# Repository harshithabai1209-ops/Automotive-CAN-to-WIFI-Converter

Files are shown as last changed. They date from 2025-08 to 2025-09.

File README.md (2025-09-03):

🚗 Automotive CAN-to-WiFi Converter(PCB DESIGN)
📌 Overview

This project implements an Automotive CAN (Controller Area Network) to Wi-Fi converter using a microcontroller with integrated Wi-Fi and a custom PCB designed in KiCad.
It allows vehicles’ CAN bus data (speed, RPM, fuel level, sensor data, etc.) to be captured, processed, and transmitted over Wi-Fi to mobile apps.

🚀 Features

Interfaces with standard Automotive CAN bus (OBD-II, ISO 11898)

Converts CAN frames into Wi-Fi packets

Supports protocols: MQTT, HTTP, WebSocket

Designed for low-latency data streaming

Custom KiCad PCB with CAN transceiver + Wi-Fi MCU

Optional SD card logging for offline analysis

Can be used for telematics, diagnostics, and fleet monitoring

🛠️ Hardware Components

Microcontroller (ESP32 / STM32 + ESP8266) → Wi-Fi + processing

CAN Transceiver (MCP2551 / SN65HVD230) → Interface between CAN bus & MCU

OBD-II Connector → Connection to vehicle CAN lines (CAN_H, CAN_L)

Power Supply

12V from car → Buck converter → 5V/3.3V regulated

Automotive-grade regulator (LM2596 / MP1584)

Protection Circuits

TVS Diodes for CAN line protection

Fuse & reverse polarity protection

Optional Modules

SD card (logging)

OLED/LCD (local display)

📐 PCB Design (KiCad)

Designed using KiCad EDA

2-layer PCB optimized for automotive use

Includes CAN transceiver + ESP32 footprint

Proper decoupling capacitors and EMI filters

Ground plane isolation between noisy CAN and Wi-Fi section

Connector footprint for OBD-II interface

Gerber files ready for fabrication

⚙️ Firmware / Software

Developed using Arduino IDE / ESP-IDF / STM32Cube

Features:

Reads CAN frames via CAN transceiver

Publishes data over Wi-Fi (MQTT/HTTP/WebSocket)

Supports real-time monitoring dashboard

Configurable baud rates (125 kbps, 250 kbps, 500 kbps)

🧩 Applications

Vehicle diagnostics (OBD-II data monitoring)

Fleet management & telematics

Real-time performance tracking (RPM, speed, fuel, etc.)

Research & development for automotive IoT

Data logging for predictive maintenance

⚠️ Safety Note

⚡ Caution: This project connects directly to the vehicle’s CAN bus. Incorrect wiring may damage ECU or other vehicle electronics. Ensure proper isolation and automotive-grade components are used.

📖 Future Enhancements

Support for Bluetooth + Wi-Fi dual mode

Cloud analytics with AI for predictive maintenance

Encryption for secure vehicle data transfer

Integration with mobile OBD-II diagnostic apps

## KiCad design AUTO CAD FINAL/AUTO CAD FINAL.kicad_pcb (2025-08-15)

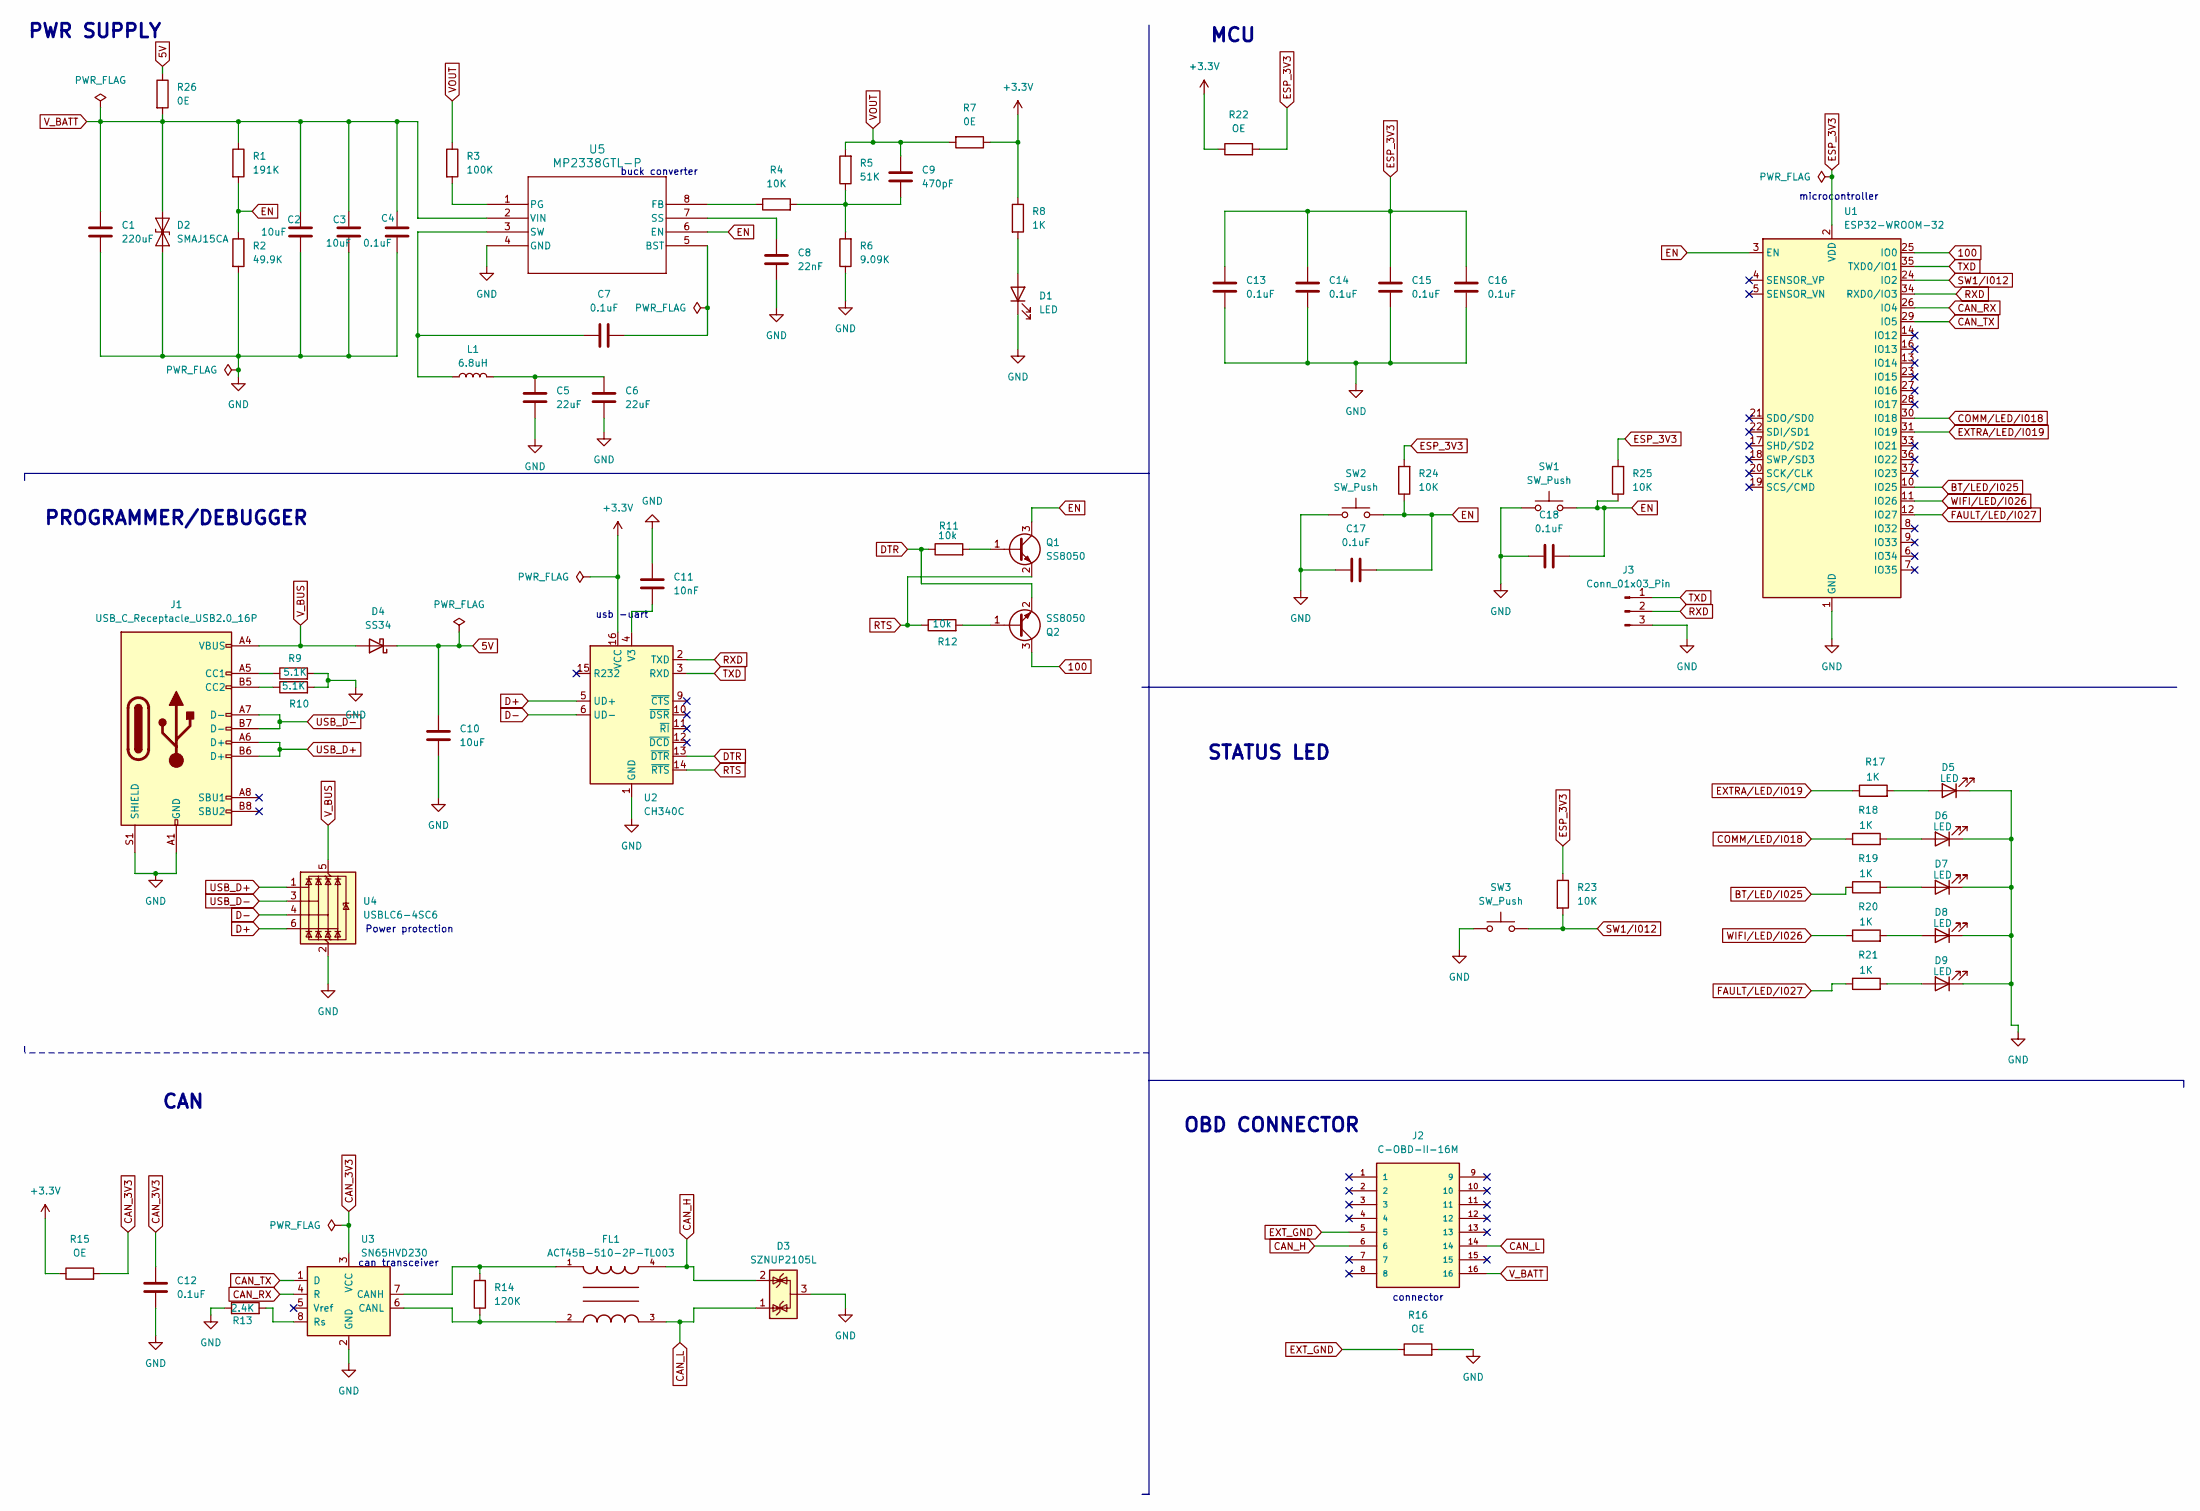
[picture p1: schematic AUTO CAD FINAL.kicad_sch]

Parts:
C1: 220uF; C_Elec_8x10.2
C2, C3, C10: 10uF; C_0603_1608Metric
C4, C7, C12, C13, C14, C15, C16, C17, C18: 0.1uF; C_0603_1608Metric
C5, C6: 22uF; C_1206_3216Metric
C8: 22nF; C_0603_1608Metric
C9: 470pF; C_0603_1608Metric
C11: 10nF; C_0603_1608Metric
D1, D5, D6, D7, D8, D9: LED; LED_0603_1608Metric
D2: SMAJ15CA; D_SMA
D3: SZNUP2105L; SOT-23
D4: SS34; D_SMA
FL1: ACT45B-510-2P-TL003; FIL_ACT45B-510-2P-TL003; PARTREV 20200405
J1: USB_C_Receptacle_USB2.0_16P; USB_C_Receptacle_HRO_TYPE-C-31-M-12
J2: C-OBD-II-16M; COMTECH_C-OBD-II-16M; PARTREV A
J3: Conn_01x03_Pin; PinHeader_1x03_P2.54mm_Vertical
L1: 6.8uH; L_6.3x6.3_H3
Q1, Q2: SS8050; SOT-23
R1: 191K; R_0603_1608Metric
R2: 49.9K; R_0603_1608Metric
R3: 100K; R_0603_1608Metric
R4, R23, R24, R25: 10K; R_0603_1608Metric
R5: 51K; R_0603_1608Metric
R6: 9.09K; R_0603_1608Metric
R7, R26: 0E; R_0603_1608Metric
R8, R17, R18, R19, R20, R21: 1K; R_0603_1608Metric
R9, R10: 5.1K; R_0603_1608Metric
R11, R12: 10k; R_0603_1608Metric
R13: 2.4K; R_0603_1608Metric
R14: 120K; R_0603_1608Metric
R15, R16, R22: OE; R_0603_1608Metric
SW1, SW2, SW3: SW_Push; SW_Push_SPST_NO_Alps_SKRK
U1: ESP32-WROOM-32
U2: CH340C; SOIC-16_3.9x9.9mm_P1.27mm
U3: SN65HVD230; SOIC-8_3.9x4.9mm_P1.27mm
U4: USBLC6-4SC6; SOT-23-6
U5: MP2338GTL-P; SOT-583-8

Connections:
5V: C10.2, D4.1 (K), R26.1
100: Q2.3 (C), U1.25 (IO0)
+3.3V: R7.1, R8.1, R15.1, R22.1, U2.16 (VCC)
BT/LED/I025: R19.1, U1.10 (IO25)
CAN_3V3: C12.2, R15.2, U3.3 (VCC)
CAN_H: D3.2 (K), FL1.4, J2.6
CAN_L: D3.1 (K), FL1.3, J2.14
CAN_RX: U1.26 (IO4), U3.4 (R)
CAN_TX: U1.29 (IO5), U3.1 (D)
COMM/LED/I018: R18.1, U1.30 (IO18)
D+: U2.5 (UD+), U4.6 (I/O4)
D-: U2.6 (UD-), U4.4 (I/O3)
DTR: Q2.2 (E), R11.1, U2.13 (~DTR)
EN: C17.1, C18.1, Q1.3 (C), R1.2, R2.1, R24.1, R25.1, SW1.2, SW2.2, U1.3 (EN), U5.6 (EN)
ESP_3V3: C13.2, C14.2, C15.2, C16.2, R22.2, R23.1, R24.2, R25.2, U1.2 (VDD)
EXTRA/LED/I019: R17.1, U1.31 (IO19)
EXT_GND: J2.5, R16.1
FAULT/LED/I027: R21.1, U1.12 (IO27)
GND: C1.2, C2.2, C3.2, C4.2, C5.2, C6.2, C8.1, C10.1, C11.2, C12.1, C13.1, C14.1, C15.1, C16.1, C17.2, C18.2, D1.1 (K), D2.1 (A1), D3.3 (A), D5.1 (K), D6.1 (K), D7.1 (K), D8.1 (K), D9.1 (K), J1.A1 (GND), J1.A12 (GND), J1.B1 (GND), J1.B12 (GND), J1.S1 (SHIELD), J3.3, R2.2, R6.1, R9.2, R10.2, R13.1, R16.2, SW1.1, SW2.1, SW3.1, U1.1 (GND), U1.15 (GND), U1.38 (GND), U1.39 (GND), U2.1 (GND), U3.2 (GND), U4.2 (GND), U5.4 (GND)
unnamed: C5.1, C6.1, L1.2
unnamed: C9.1, R4.2, R5.1, R6.2
unnamed: D1.2 (A), R8.2
unnamed: D5.2 (A), R17.2
unnamed: D6.2 (A), R18.2
unnamed: D7.2 (A), R19.2
unnamed: D8.2 (A), R20.2
unnamed: D9.2 (A), R21.2
unnamed: J1.A5 (CC1), R9.1
unnamed: J1.B5 (CC2), R10.1
unnamed: Q1.1 (B), R11.2
unnamed: Q2.1 (B), R12.2
unnamed: C11.1, U2.4 (V3)
unnamed: FL1.1, R14.2, U3.7 (CANH)
unnamed: FL1.2, R14.1, U3.6 (CANL)
unnamed: R13.2, U3.8 (Rs)
unnamed: C7.2, U5.5 (BST)
unnamed: R4.1, U5.8 (FB)
unnamed: R3.2, U5.1 (PG)
unnamed: C8.2, U5.7 (SS)
unnamed: C7.1, L1.1, U5.3 (SW)
RTS: Q1.2 (E), R12.1, U2.14 (~RTS)
RXD: J3.2, U1.34 (RXD0/IO3), U2.2 (TXD)
SW1/I012: R23.2, SW3.2, U1.24 (IO2)
TXD: J3.1, U1.35 (TXD0/IO1), U2.3 (RXD)
USB_D+: J1.A6 (D+), J1.B6 (D+), U4.1 (I/O1)
USB_D-: J1.A7 (D-), J1.B7 (D-), U4.3 (I/O2)
VOUT: C9.2, R3.1, R5.2, R7.2
V_BATT: C1.1, C2.1, C3.1, C4.1, D2.2 (A2), J2.16, R1.1, R26.2, U5.2 (VIN)
V_BUS: D4.2 (A), J1.A4 (VBUS), J1.A9 (VBUS), J1.B4 (VBUS), J1.B9 (VBUS), U4.5 (VBUS)
WIFI/LED/I026: R20.1, U1.11 (IO26)

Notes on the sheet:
MCU
usb -uart
connector
can transceiver
microcontroller
OBD CONNECTOR
CAN
PWR SUPPLY
buck converter
Power protection
PROGRAMMER/DEBUGGER
STATUS LED

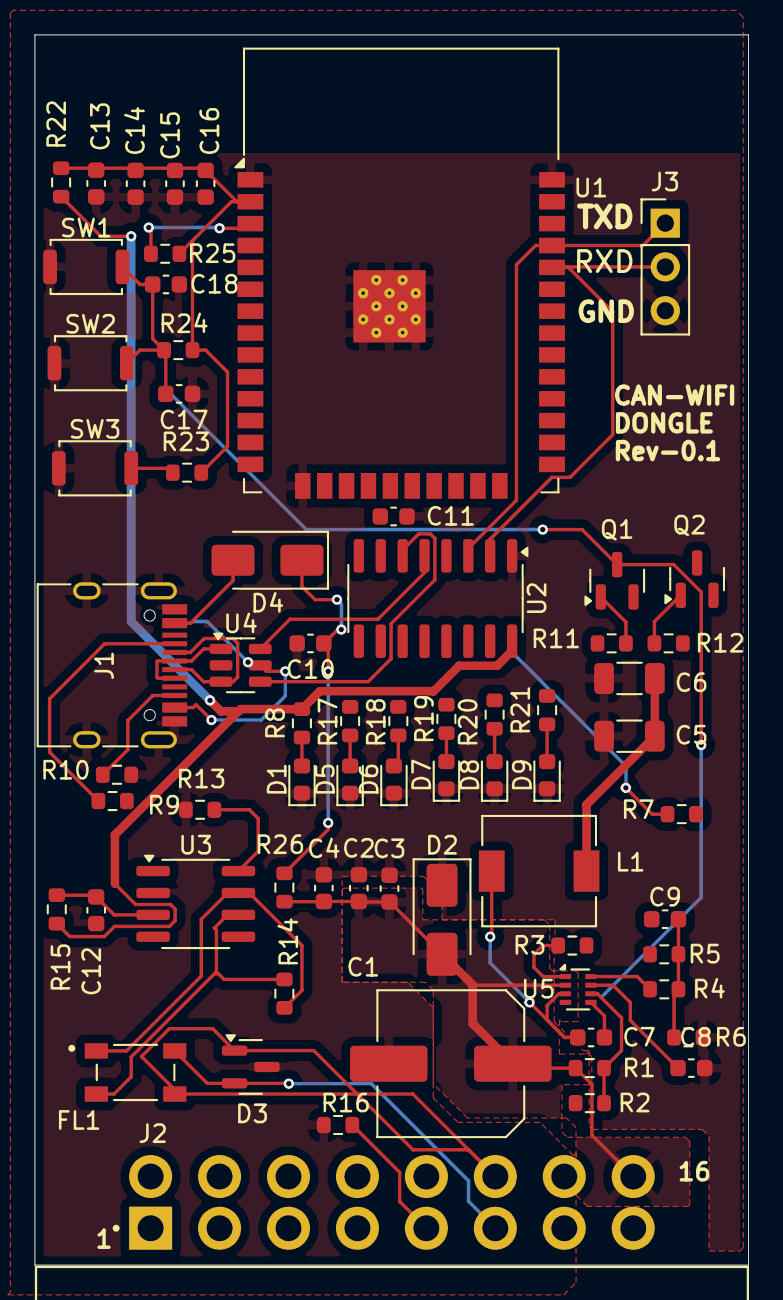
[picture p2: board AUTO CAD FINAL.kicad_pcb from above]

Board: 2 copper layers, 41.4 x 71.4 mm, 68 parts (0 on the bottom side), 50 nets.
